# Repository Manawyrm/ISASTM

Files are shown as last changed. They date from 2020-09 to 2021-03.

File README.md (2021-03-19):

ISASTM
=============================

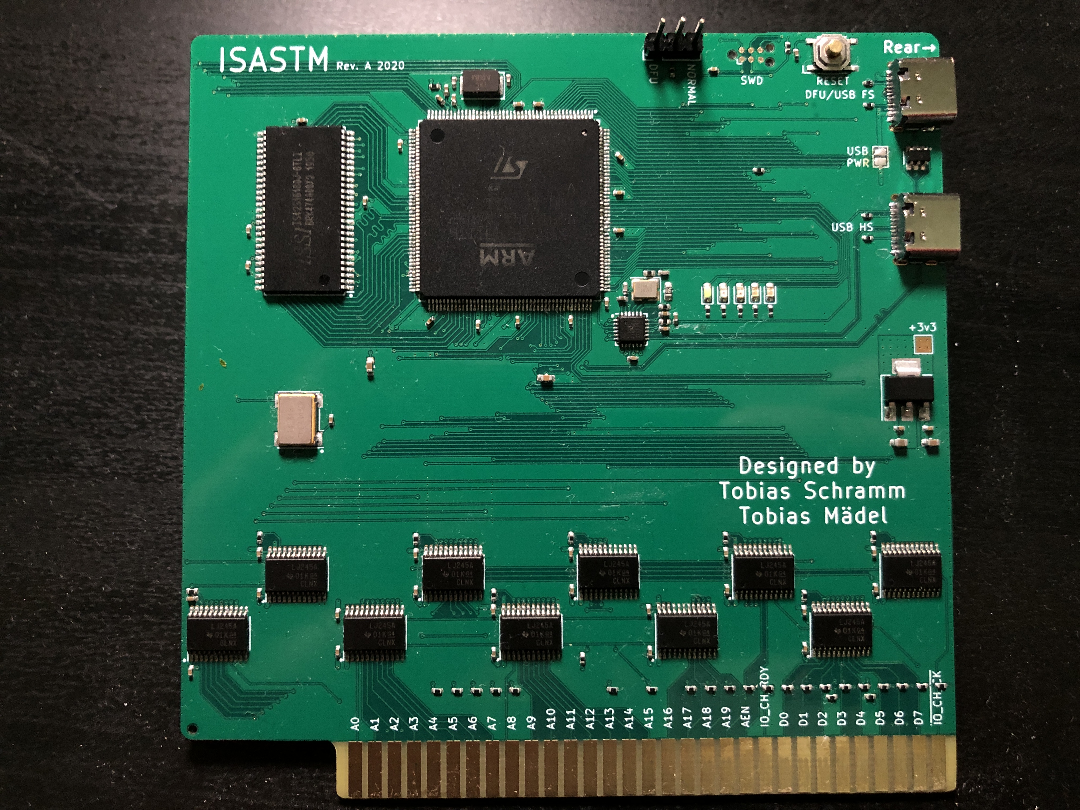
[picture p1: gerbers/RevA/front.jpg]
Photo of ISASTM PCB


### Overview

ISASTM is an ISA host using a STM32H743 CPU, 32 MiB SDRAM and USB 2.0 Full-Speed / High-Speed.  
It can enable ISA cards to be used inside a VM or even emulate an x86 PC internally with an external ISA bus. 

The card is designed to be used with an ISA backplane, which supplies power and connects the ISA slots.  
The design is optimized for automated assembly at [JLCPCB](https://jlcpcb.com/DDE). 

### Errata Rev. A
- Signal integrity issues, level shifters seem to drive the bus too hard. Maybe 33R series resistance.
- Reset line is missing a pull up on the ISA bus/HV side
- USB 2.0 High speed (480 MBit/s) untested, might not work.

### Additional info

[Firmware](https://github.com/Manawyrm/ISASTM-Firmware)  
[Schematic](https://github.com/Manawyrm/ISASTM/blob/master/gerbers/RevA/ISASTM.pdf)  
  
[Twitter: Project thread](https://twitter.com/Manawyrm/status/1302558858360033280)  

### Credits
Thanks to [@Toble_Miner](https://github.com/TobleMiner) for layouting the PCB!

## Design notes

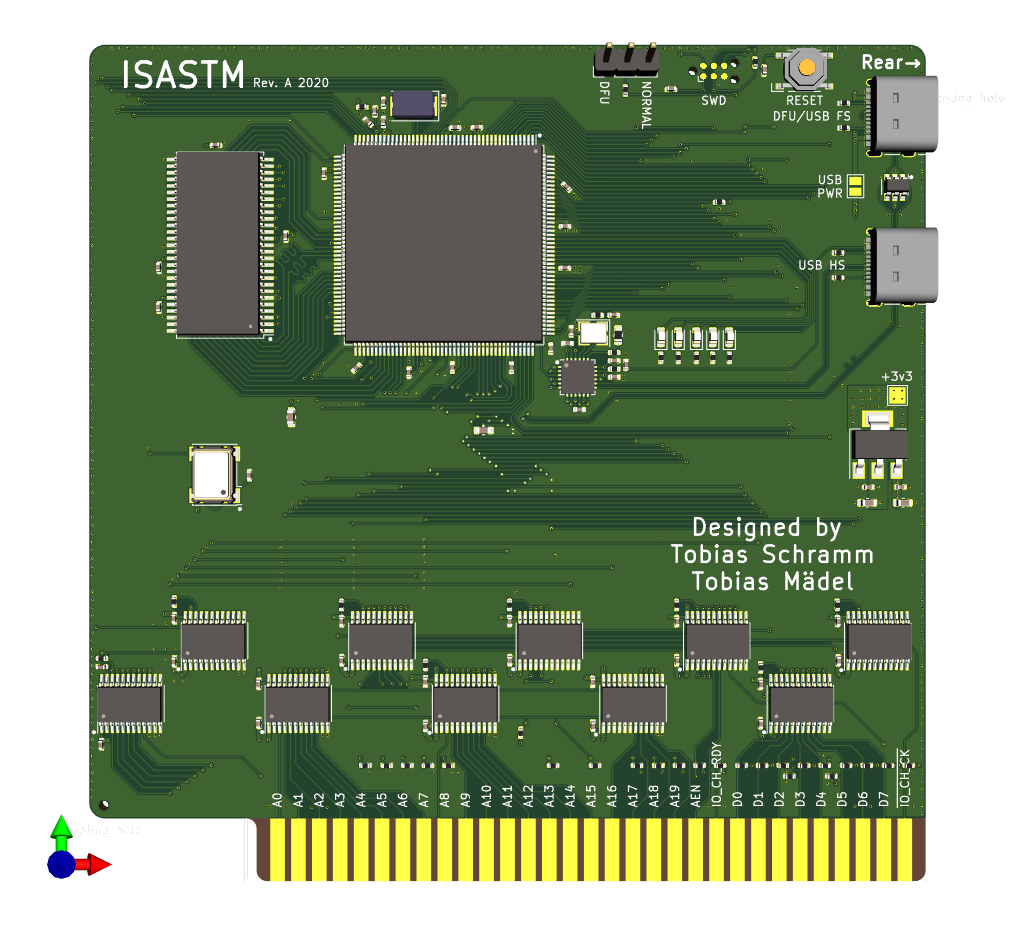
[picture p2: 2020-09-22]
gerbers/RevA/front.png

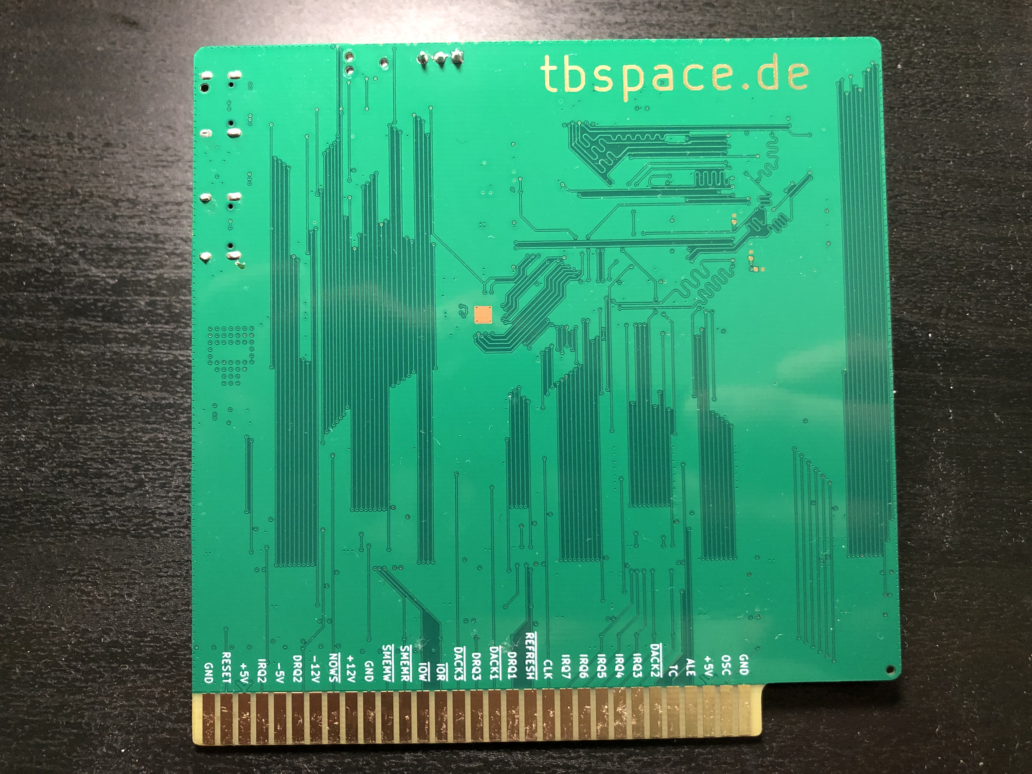
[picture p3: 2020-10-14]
gerbers/RevA/back.jpg

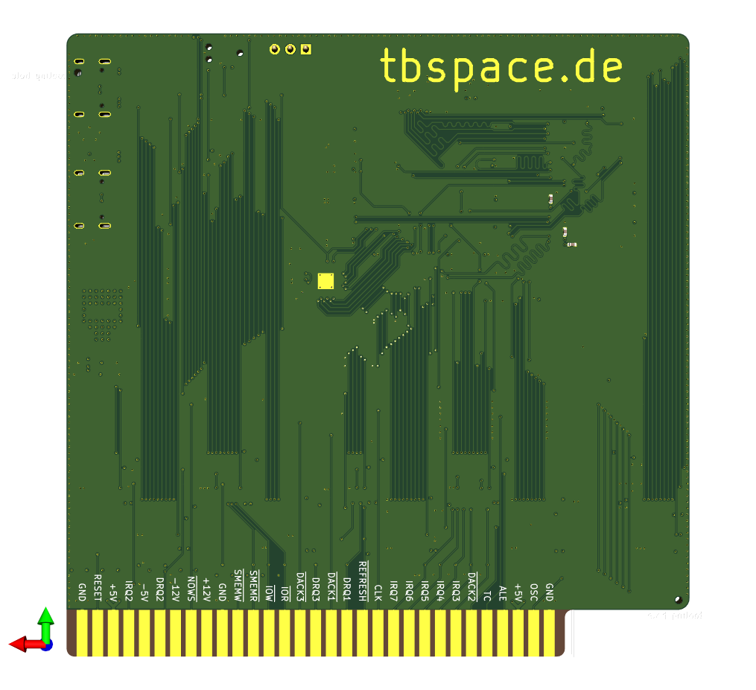
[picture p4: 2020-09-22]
gerbers/RevA/back.png

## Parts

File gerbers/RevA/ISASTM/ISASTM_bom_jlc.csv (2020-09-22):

Comment | Designator | Footprint | LCSC Part #
2.2u | C1,C2 | C_0603_1608Metric | C23630
20p | C5,C6 | C_0402_1005Metric | C1554
1u | C7,C33,C11,C4,C10 | C_0402_1005Metric | C52923
6.8pF | C8,C3 | C_0402_1005Metric | C1576
100n | C13,C16,C20,C24,C27,C29,C22,C31,C36,C14,C17,C21,C25,C28,C32,C37,C15,C19,C23,C26,C30,C35,C38,C9,C12,C39,C42,C44,C46,C48,C40,C52,C54,C56,C58,C50,C43,C45,C47,C49,C41,C53,C55,C57,C59,C51 | C_0402_1005Metric | C1525
10u | C18 | C_0603_1608Metric | C19702
22u | C34 | C_0603_1608Metric | C59461
White | D1 | LED_0603_1608Metric | C2290
Red | D2 | LED_0603_1608Metric | C2286
Yellow | D3 | LED_0603_1608Metric | C72038
Green | D4 | LED_0603_1608Metric | C72043
Blue | D5 | LED_0603_1608Metric | C72041
10k | R1,R7,R3,R4,R5,R6,R9,R10,R11,R12 | R_0402_1005Metric | C25744
10R | R2 | R_0402_1005Metric | C25077
100k | R8,R41,R42,R43,R44,R45,R46,R47,R48,R29,R30,R31,R32,R33,R34,R26,R27,R28 | R_0402_1005Metric | C25741
5.1k | R13,R14,R15,R16,R21,R22,R23,R24,R25 | R_0402_1005Metric | C25905
1M | R17 | R_0402_1005Metric | C26083
20k | R18 | R_0402_1005Metric | C25765
7.5k | R19 | R_0402_1005Metric | C25918
560R | R20 | R_0603_1608Metric | C23204
1k | R35 | R_0402_1005Metric | C11702
4.7k | R36,R37,R38,R39,R40,R49 | R_0402_1005Metric | C25900
Reset | SW1 | TS-1187A-X-X-X | C318887
STM32H743IITx | U1 | LQFP-176_24x24mm_P0.5mm | C89597
IS42S16160J-6TLI | U2 | TSOP-II-54_22.2x10.16mm_P0.8mm | C91278
AMS1117-3.3 | U5 | SOT-223-3_TabPin2 | C6186
SN74AVC8T245PW | U9,U3,U4,U10,U6,U7,U8,U13,U11,U12 | TSSOP-24_4.4x7.8mm_P0.65mm | C7859
SRV05-4 | U14 | SOT-23-6 | C85364
14.31818 MHz | X1 | Oscillator_SMD_SeikoEpson_SG8002CA-4Pin_7.0x5.0mm | C70517
26 MHz | Y1 | Crystal_SMD_3225-4Pin_3.2x2.5mm | C91747
8 MHz | Y2 | Crystal_SMD_5032-2Pin_5.0x3.2mm | C115962

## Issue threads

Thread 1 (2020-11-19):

List of tested ISA cards

kuenzign, 2020-11-19:
This looks like a great project and it's very exciting.  I think that in order to gain more support from the community, it would be a good idea to provide a list of cards that have been tested with the ISASTM (showing which cards **do not** work and cards that **do** work).  Personally, I have been hoping that ISA floppy controllers would work, but that's probably a bit of a pipe dream.  Thanks for the hard work!

Manawyrm, 2020-11-19:
Hey,

so, in general every 8bit ISA card is able to be supported.
There are 2 main issues:
a) real-time operation
b) USB latency / frame-timings

The other issues like missing/very broken DMA support are just software problems and could be fixed in the firmware.

The lack of real-time operation (because the emulator isn't always running at 100% CPU speed and can vary it's frequency by quite a bit) is normally not an issue, but for specific applications like measurements, motor control (think old CNC machine controllers, etc.) this will be a big issue. I don't see any way to support this kind of device.

The USB standard requires a minimum frame time of 1ms per frame (125µs for USB 2.0 HS), which means you will need at least 2ms for a single byte transfer. Writing data can be done a lot more efficient/faster with clever coding, but reads are always bottlenecked by this.

I have successfully used:
- a floppy controller card (with a flash floppy USB emulator thingy)
- a serial port card
- a parallel port card
- a port 80h diagnostic card
- several sound blaster card (using the AdLib functionality)
- a Creative Gameblaster card
- several VGA cards
- a RTL8019 network card

Things that don't work (and why):
- Sound Blaster (digital sound, needs properly working DMA support, pretty sure fixable)
- IDE controller cards (need upper 16bit IRQs and 16bit data for ATAPI commands, no supported by hardware)

In general, the USB idea was pretty okay for a proof-of-concept, but if you would want to actually use this thing for any real usage, the board would need to be redesigned to use something like an FPGA and use a bus like PCI.
Talking via Thunderbolt/PCIe/PCI to a media bridge and letting it map the ISA bus 1:1 would work much, much better.
Interrupts could be handled as MSIs, DMA would just be done as writes/reads to a mailbox (probably?!).

But I don't think I'm going to implement that anywhere in the near future.

Best regards,
Tobias

toncho11, 2020-12-03:
Hi,

Great project!

So how does it work exactly? I want to use a 360 KB floppy and controller on Windows 10.
So I need to build and put your card and the floppy controller on an ISA backplane.
But then we need a Windows driver that will emulate the floppy on Windows? This part I do not understand.

Manawyrm, 2020-12-04:
Hi toncho,

this project is converts a set of USB messages to actions on an ISA bus.
In theory, yes, you could build a Windows driver for it.
I don't think that's a useful thing, though.

What you'd do is start an emulator (like PCem) and do your work in there (with the "real" floppy being pass-through).

The project is not a point where it is usable for any proper work, at all, though.
I would NOT recommend you go build one of these, unless you want to find out every single little detail about the ISA bus.

If you want to work with floppy drives, use Greaseweazle, KryoFlux or similar:
https://github.com/keirf/Greaseweazle
https://www.kryoflux.com/
They are easier to assemble and will do what you need, much better and easier.

Best regards,
Tobias

laf0rge, 2022-01-28:
I have a number of questions about this project, and since there seems to be no mailing-list or forum, I'm hijacking this github issue for it..

> so, in general every 8bit ISA card is able to be supported. [...]]

Is there a specific reason to go for 8-bit ISA only?  The rather high-end microcontroller chosen should have plenty of additional I/O pins around?

> The USB standard requires a minimum frame time of 1ms per frame (125µs for USB 2.0 HS), which means you will need at least 2ms for a single byte transfer. Writing data can be done a lot more efficient/faster with clever coding, but reads are always bottlenecked by this.

The question here is whether 125us (x2) is "good enough" for most use cases or not.  Sure, FS-USB 2ith 1ms (x2) is probably stretching it a bit too far for any but the most trivial use cases.

> In general, the USB idea was pretty okay for a proof-of-concept, but if you would want to actually use this thing for any real usage, the board would need to be redesigned to use something like an FPGA and use a bus like PCI. Talking via Thunderbolt/PCIe/PCI to a media bridge and letting it map the ISA bus 1:1 would work much, much better. Interrupts could be handled as MSIs, DMA would just be done as writes/reads to a mailbox (probably?!).

That's of course a completely different complexity (schematics, layout, cost, ...), and a bit overkill for the good old ISA, IMHO.

btw; any spcific reason for putting 32MiB of SDRAM in the design?  The use case of translating small MMIO / PIO transactions between USB transfers and the ISA bus doesn't really look like anything that would be very memory-heavy.  Just trying to find the reason for the design decision to understand the project better.

Thanks!

Manawyrm, 2022-01-28:
> since there seems to be no mailing-list or forum

True, I have a nasty habit of abandoning projects after I get bored with them :laughing:
But you know my Twitter account and IRC handle :)

> Is there a specific reason to go for 8-bit ISA only?

Yes, it's a 4-layer board and back then going over 10x10cm was very expensive (for a hobby project) at JLCPCB.
I think that's changed by now, so a second revision might be useful.

> The question here is whether 125us (x2) is "good enough" for most use cases or not.

Yes, but USB 2.0 is broken on the card. I'm still not a fan of USB, but I'm fairly certain that the STM32 is incompatible with the USB PHY due to a hardware bug. There are other ULPI PHYs that should be compatible (USB3300 maybe? untested.).

I wanted to do "retro fun" stuff like attaching VGA cards and sound cards via USB, especially VGA scrolling via 1ms latency was getting very painfully slow.
For stuff like machine control, sensor aquisition, etc. it might be perfectly fine?
Just a small caveat: IRQ support is experimental at best, DMA support is practically non-existant. I/O works pretty well.

>  any spcific reason for putting 32MiB of SDRAM in the design?

Yes! :smile:
We've ported a full 486 emulator onto the plattform and were able to get the card to run a "full" computer all by itself.
Unfortunately, it only boots into the BIOS and it fails after the memory check (which only goes up to 640KB, although 4MB are available). I think it's something to do with 32bit alignment, but I wasn't able to figure out what the exact issue is.

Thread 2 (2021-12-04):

This is really neet and thinking of forking it.

WarlockD, 2021-12-04:
Ever thought of using a Cypress chip?  Its basically an ARM with some logic blocks to do stuff like bus arbitration and has a built in usb 2.0 port.  Whats best is it can run at 5 volts at 48mhz.  I think I will experiment with it a bit to see if I can get it to work but either way love your project and be building it as soon as I find the chilps:P

Manawyrm, 2021-12-04:
Yup, I also have an FX3 USB3.0 board here to play around with.

In the end, USB is just the wrong protocol for this kind of application. Each bus transaction takes a very long fixed time due to USB frame lengths and this makes the result almost unusably slow.

A better interface like PCIe (or Thunderbolt), maybe Firewire would be required for proper operation.

laf0rge, 2022-01-28:
> A better interface like PCIe (or Thunderbolt), maybe Firewire would be required for proper operation.

did you ever think of LPC-to-ISA bridges?  There are quite a number of x86 boards around where access to LPC is possible.

Manawyrm, 2022-01-28:
Yes! I sniffed around on the LPC of a machine I had, but the mapped memory regions were quite limited.

I was thinking about doing something like a PCI card with 2 memory BARs:
1 memory BAR would translate all R/W into ISA I/O R/W
1 memory BAR would translate all R/W into ISA Memory R/W
and maybe another space for a mailbox for interrupts, DMA, etc.

That should be very easy to implement in x86 emulators and should also work on something like a Raspberry Pi. (I'm still dreaming of an ISA card with a Compute Module 4, which could emulate the CPU while having real peripherals)

Manawyrm, 2022-01-28:
I actually have a nice PCI devboard here and was playing around with it, but I'm not experienced enough with FPGAs yet to implement the timings and state machine for the PCI->ISA conversion.
Then I also accepted a new job, so my time for retro fun is even more limited :cry:

laf0rge, 2022-01-28:
> Yes! I sniffed around on the LPC of a machine I had, but the mapped memory regions were quite limited.

I'm pondering to build something around a fintek LPC2ISA bride, and hooking that up to the LPC header of a PC-Engines APU2.  That's a neat little fanless embedded x86_64 board (with schematics available). And as it has the LDRQ0# signal connected to the LPC header, so even ISA DMA should be possible.

> I was thinking about doing something like a PCI card with 2 memory BARs: 1 memory BAR would translate all R/W into ISA I/O R/W 1 memory BAR would translate all R/W into ISA Memory R/W and maybe another space for a mailbox for interrupts, DMA, etc.

interesting idea.  But indeed more a HDL/FPGA kind of task, rather than a board-level circuit design aroun existing ICs + software development kind of task.  The latter of which seem to be falling more into both of our comfort zone..

WarlockD, 2022-03-03:
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

I agree and it looks somone beat us to the punch.
https://www.aliexpress.com/item/1005002622355949.html?spm=a2g0o.order_list.0.0.21ef1802t2BaDU
Its a PCIE bus to ISA converter board.  I think its more designed so you can interface embeded pcie things with leagcy electronics, but its 5v safe, LQFP-64 small, has a seperate spi and a few gpio independent pins with seperate 8 bit data/address lines.
I ordered one of these and the CH368 Development board.  The main diffrence is the 368 supports a 16 bit address space and a 32bit word data path with separate IOP and MEM access pins.  Hell there are even signed windows 10 drivers for these things for both passthough and direct development.

Won't really know how well it works till I get it latter this month though.  The chip maker has the drivers and a header for its dll and its simple enough to use.  Funny enough it looks like this thing has been out since 2011 (At least that's the date on the header) so kind of surprised they never advertised it more.

WarlockD, 2022-03-03:
As a side note, I also have evaluated the Arstech device, thinking I rather drop a pound to save a ton.  Nope.  ARG the rant I can go on that API when all it is just a FX2 directly connected to the ISA bus.  It works though, but its stupid app is running 100% on one of the cpus and does cross process function direct pointer calls, *shutter*

Manawyrm, 2022-03-03:
@WarlockD The CH368 actually looks really promising!
Have you found a dev board for the CH368 with an ISA connector directly attached?

WarlockD, 2022-03-10:
Sadly no, I got both of them in.  Intresting about them is they both have this 4 pin connector that has 8bits of address, 8bits of data and all the signal lines.  So I could run a 4pin ribbon cable to say a backplane.  The CH368 has a second 40 pin connector that has the other 24bit data, the upper 8bit address and singles for the spi/ extra gpio etc.

Right now trying to get a computer together for it and going to see if I can get my soundblaster to work on it.  It only needs io to run.  Also found some linux drivers for this to.

Real question is how to build something from this.  It dosn't look like you need to use buffers like you would on the ISASTM, however since its a pcie bus, your limited to like a 2 foot usb 3.0 cord if your extending it that way.  I think you could get a way with a 40 pin ide cable to an adaptor plate.  Humm I will see if I can make such a plate, I wonder if they make cases that take two motherboards.

jamesfmackenzie, 2023-09-24:
Catching up on this thread in 2023! Did you ever make progress with the CH368? I noticed this newer revision. Looks similar to the older CH368 but with an onboard FPGA:

Pcie Development Board CH368 Development Board Pcie-FPGA Development Board
https://a.aliexpress.com/_mqNw0Bg

Does that hold some extra interest?

WarlockD, 2023-09-28:
Not really, got pulled away by other things.  I did mange to spider wire together the CH368 16bit board to a vga card and get it to run.  The issue I couldn't get away from though is that I couldn't think of a way for it to emulate something a bios would recognize.  This is an interface from PCIE to 16bit ISA, not the other way around so I cannot monitor things like address changes or such.  Maybe as a connection to a CM4 raspberry pi (That's the pi that has a PCIE exposed) You could use a set of tri-state registers and monitor the isa bus, but I haven't scoped the connection to see if the chip can go fast enough to catch edges.  But again the chip is cheap, requires little to no external components and the driver software is easy to use.

Honestly I have been looking at those dirt cheap 20k LUT Chinese FPGA's.  Like under 20 bucks.  That's more than enough for a complete NES and more than enough for any kind of video emulation.  But again, things like this keep me moving around without focus so sorry I couldn't be much more help.

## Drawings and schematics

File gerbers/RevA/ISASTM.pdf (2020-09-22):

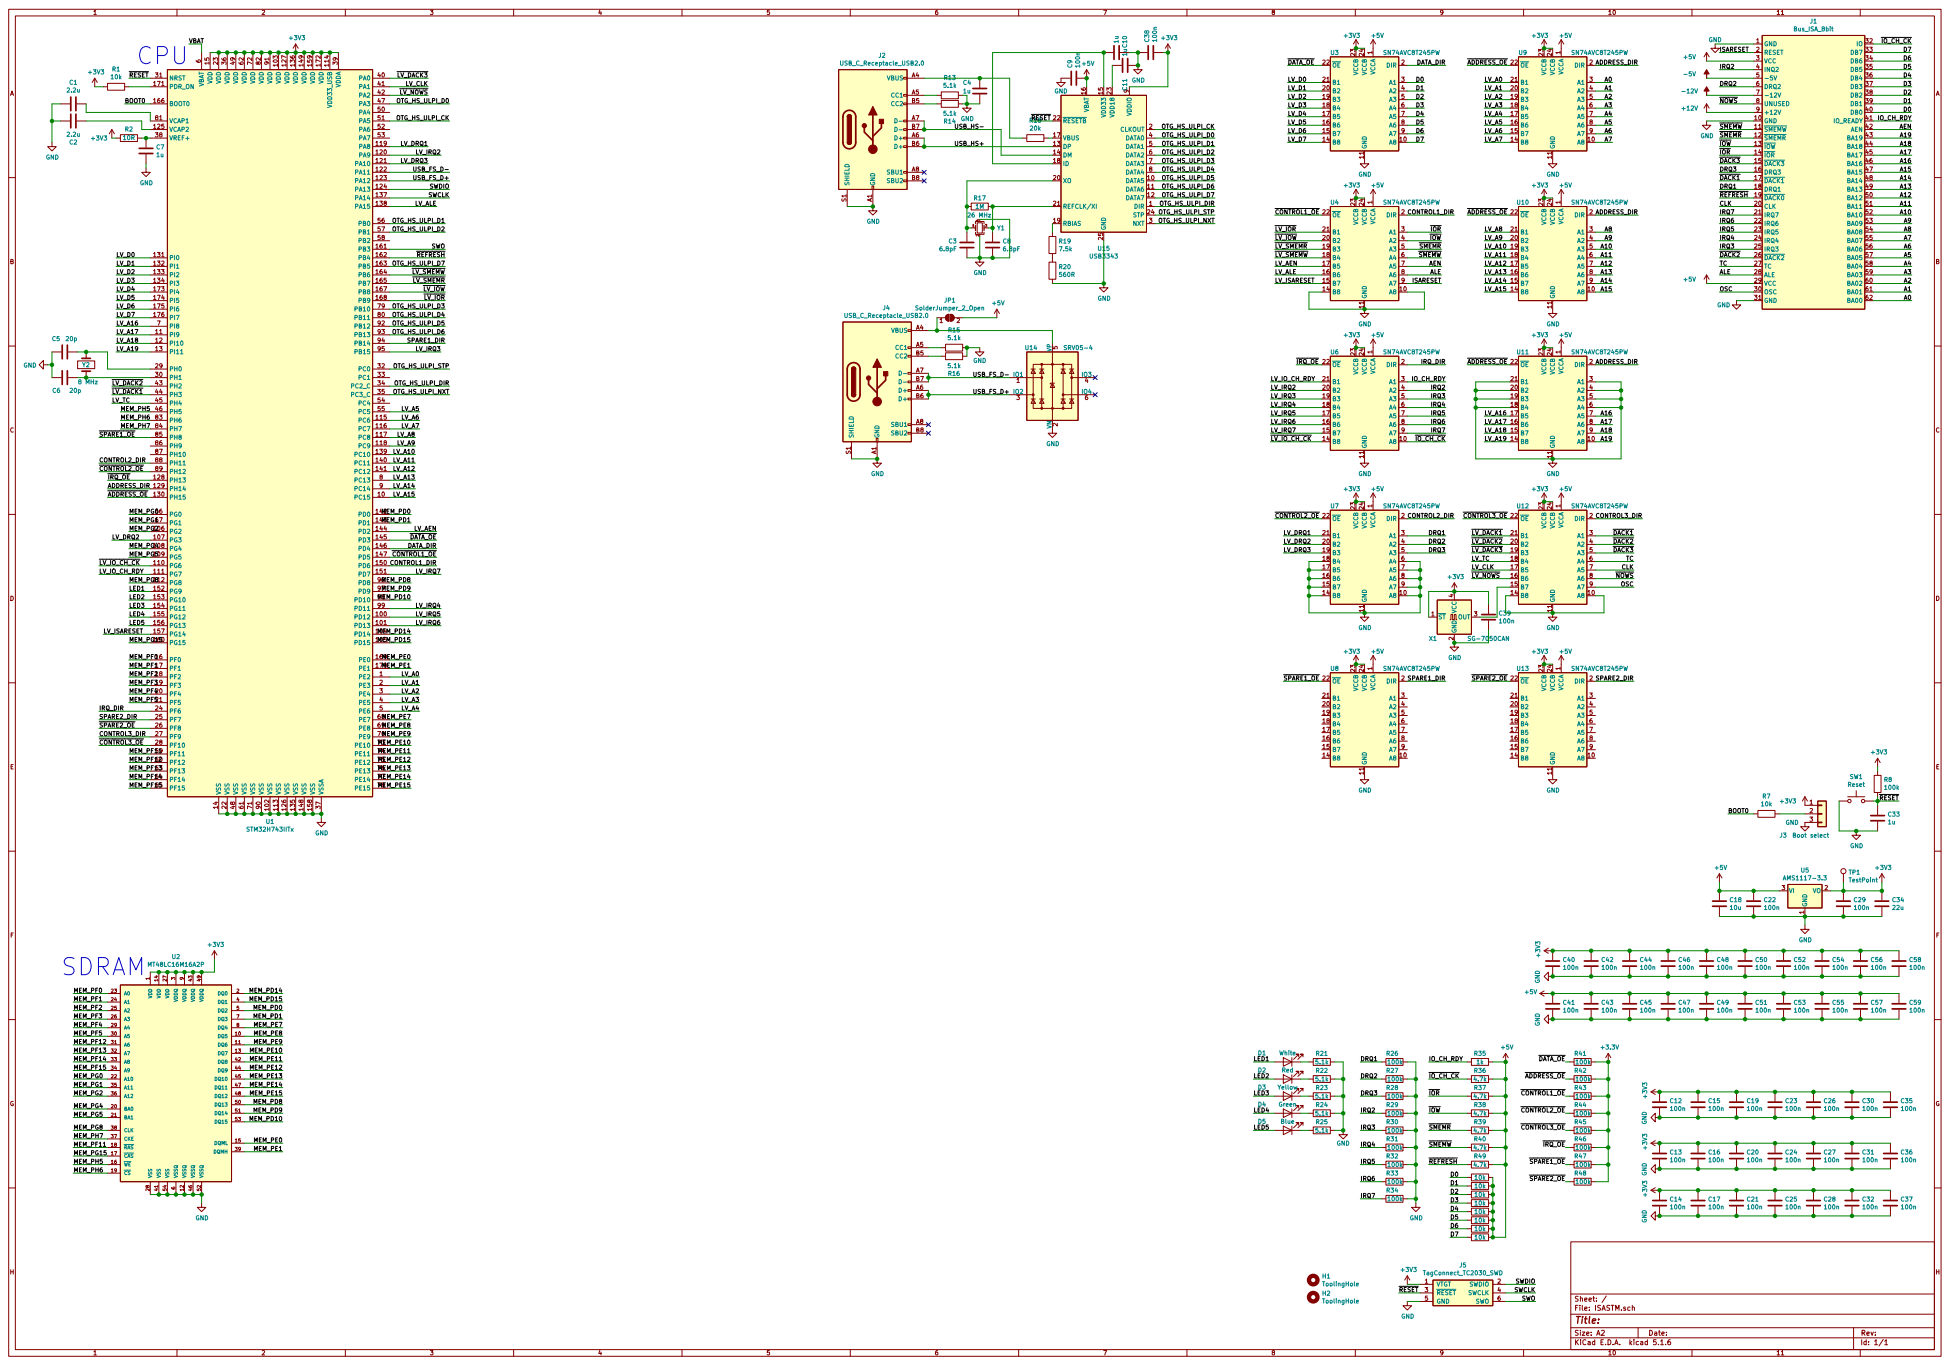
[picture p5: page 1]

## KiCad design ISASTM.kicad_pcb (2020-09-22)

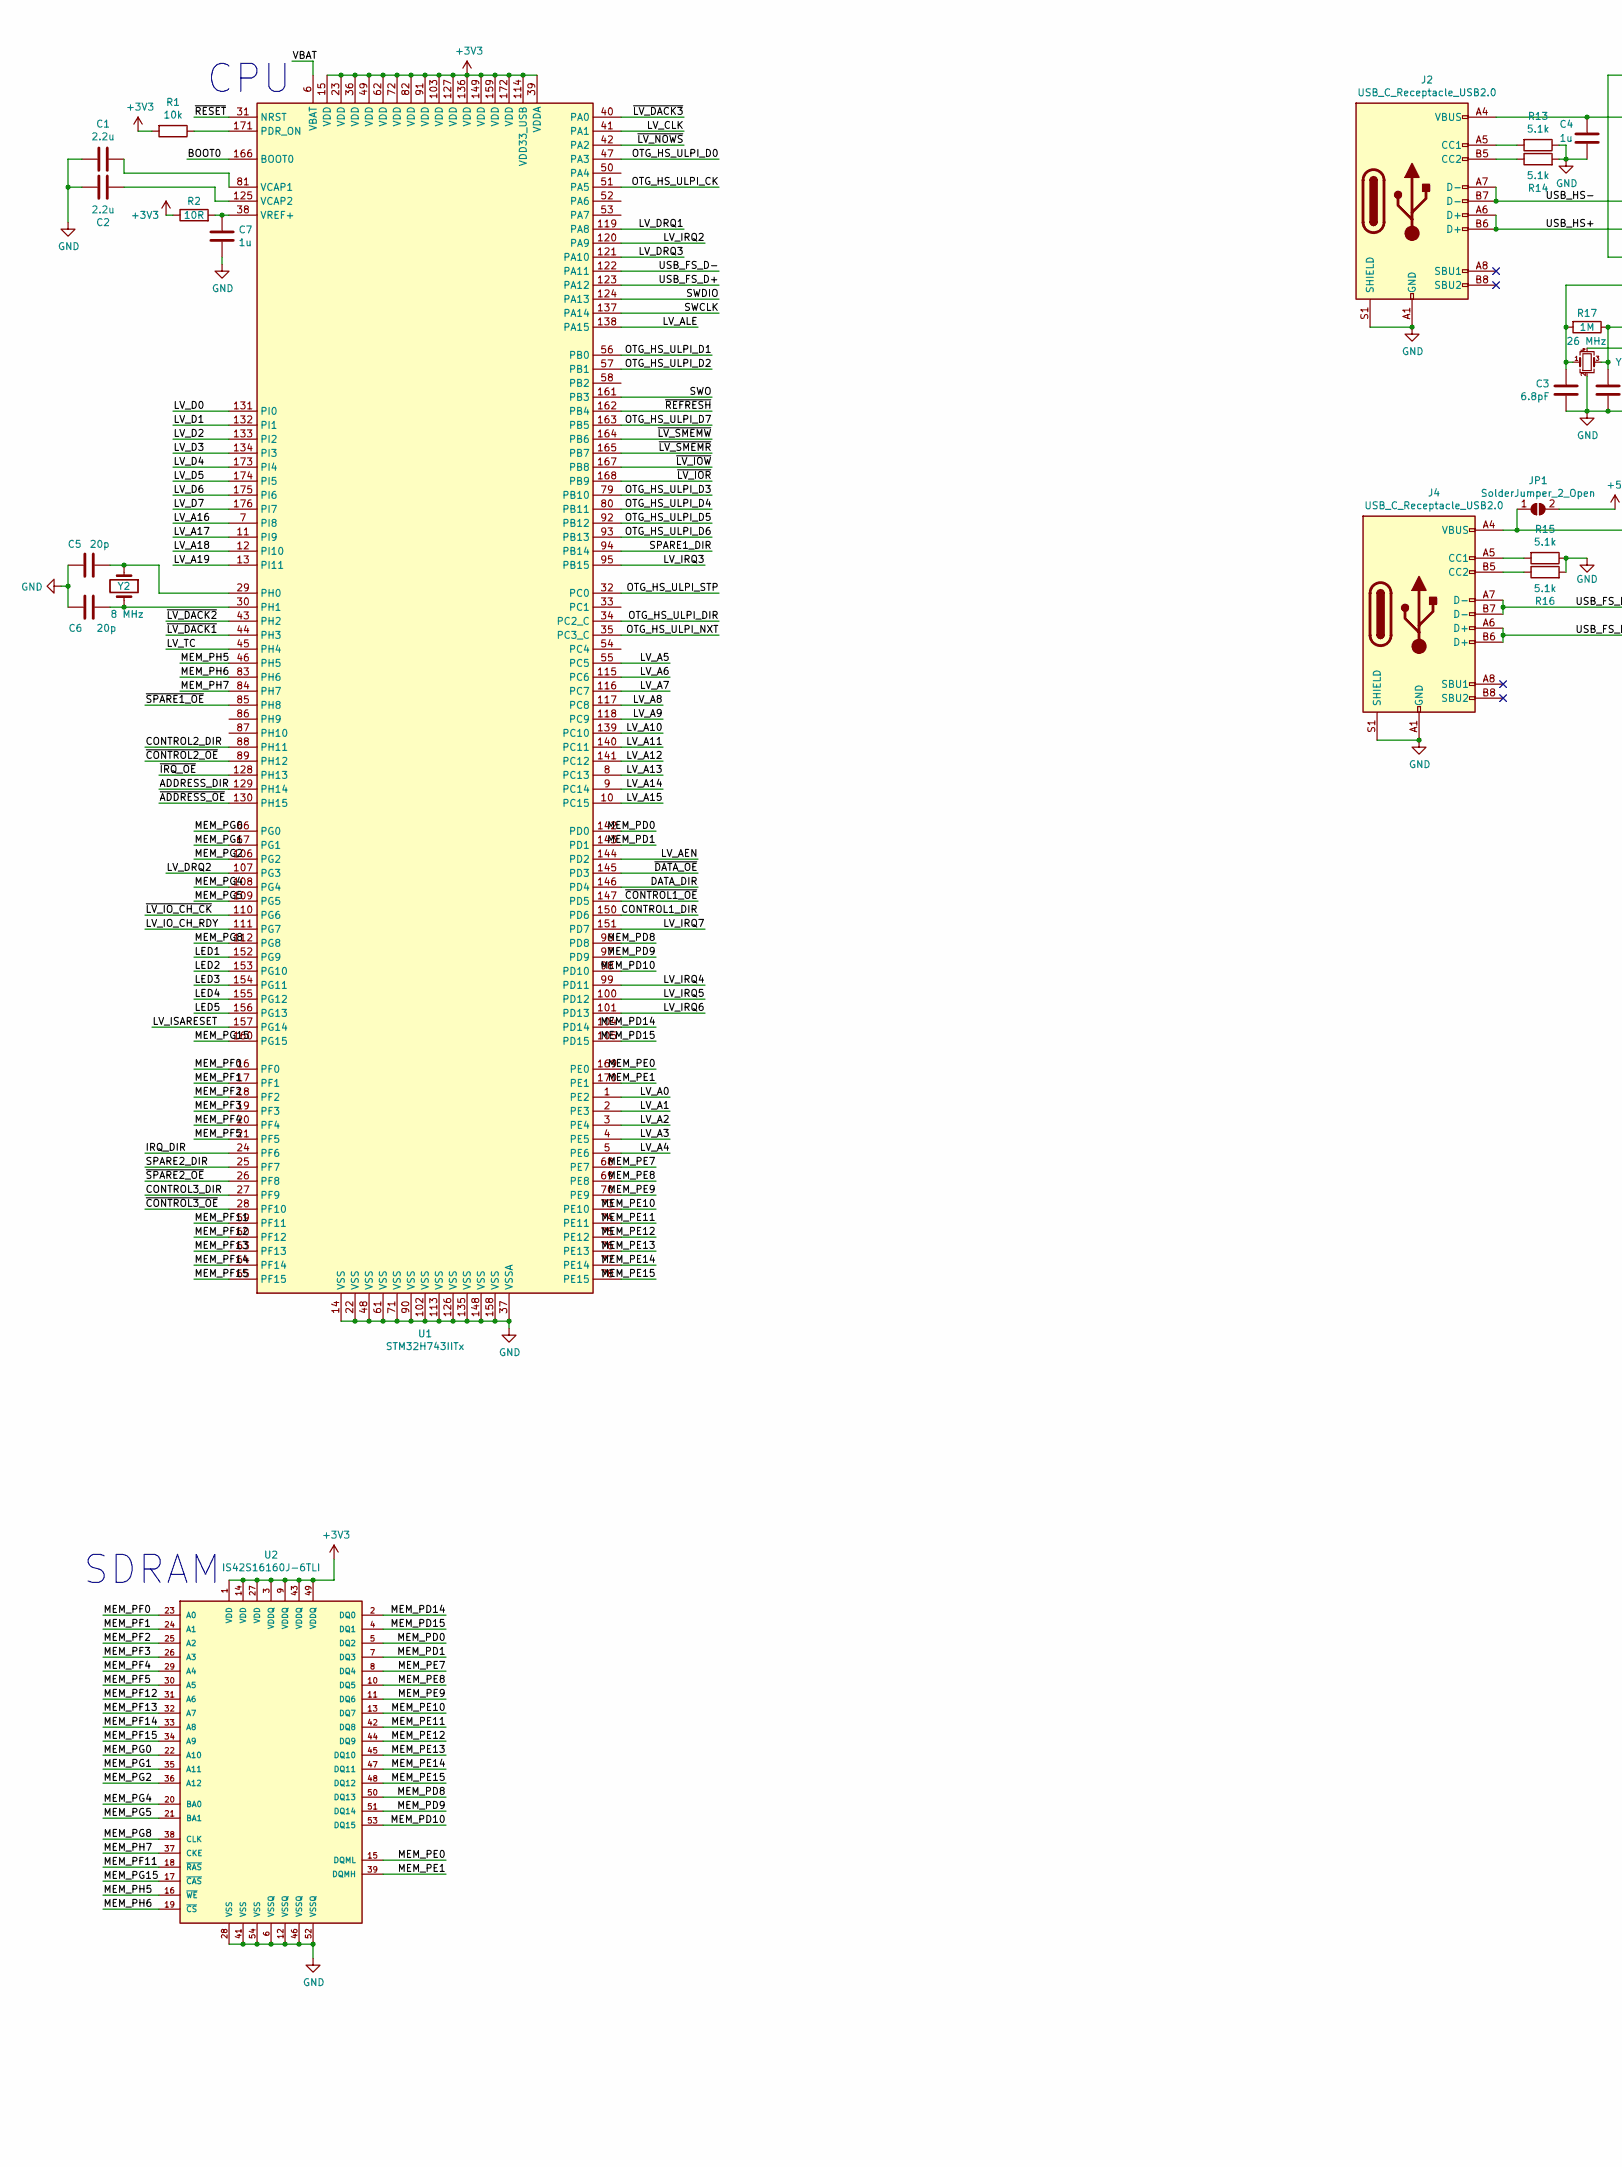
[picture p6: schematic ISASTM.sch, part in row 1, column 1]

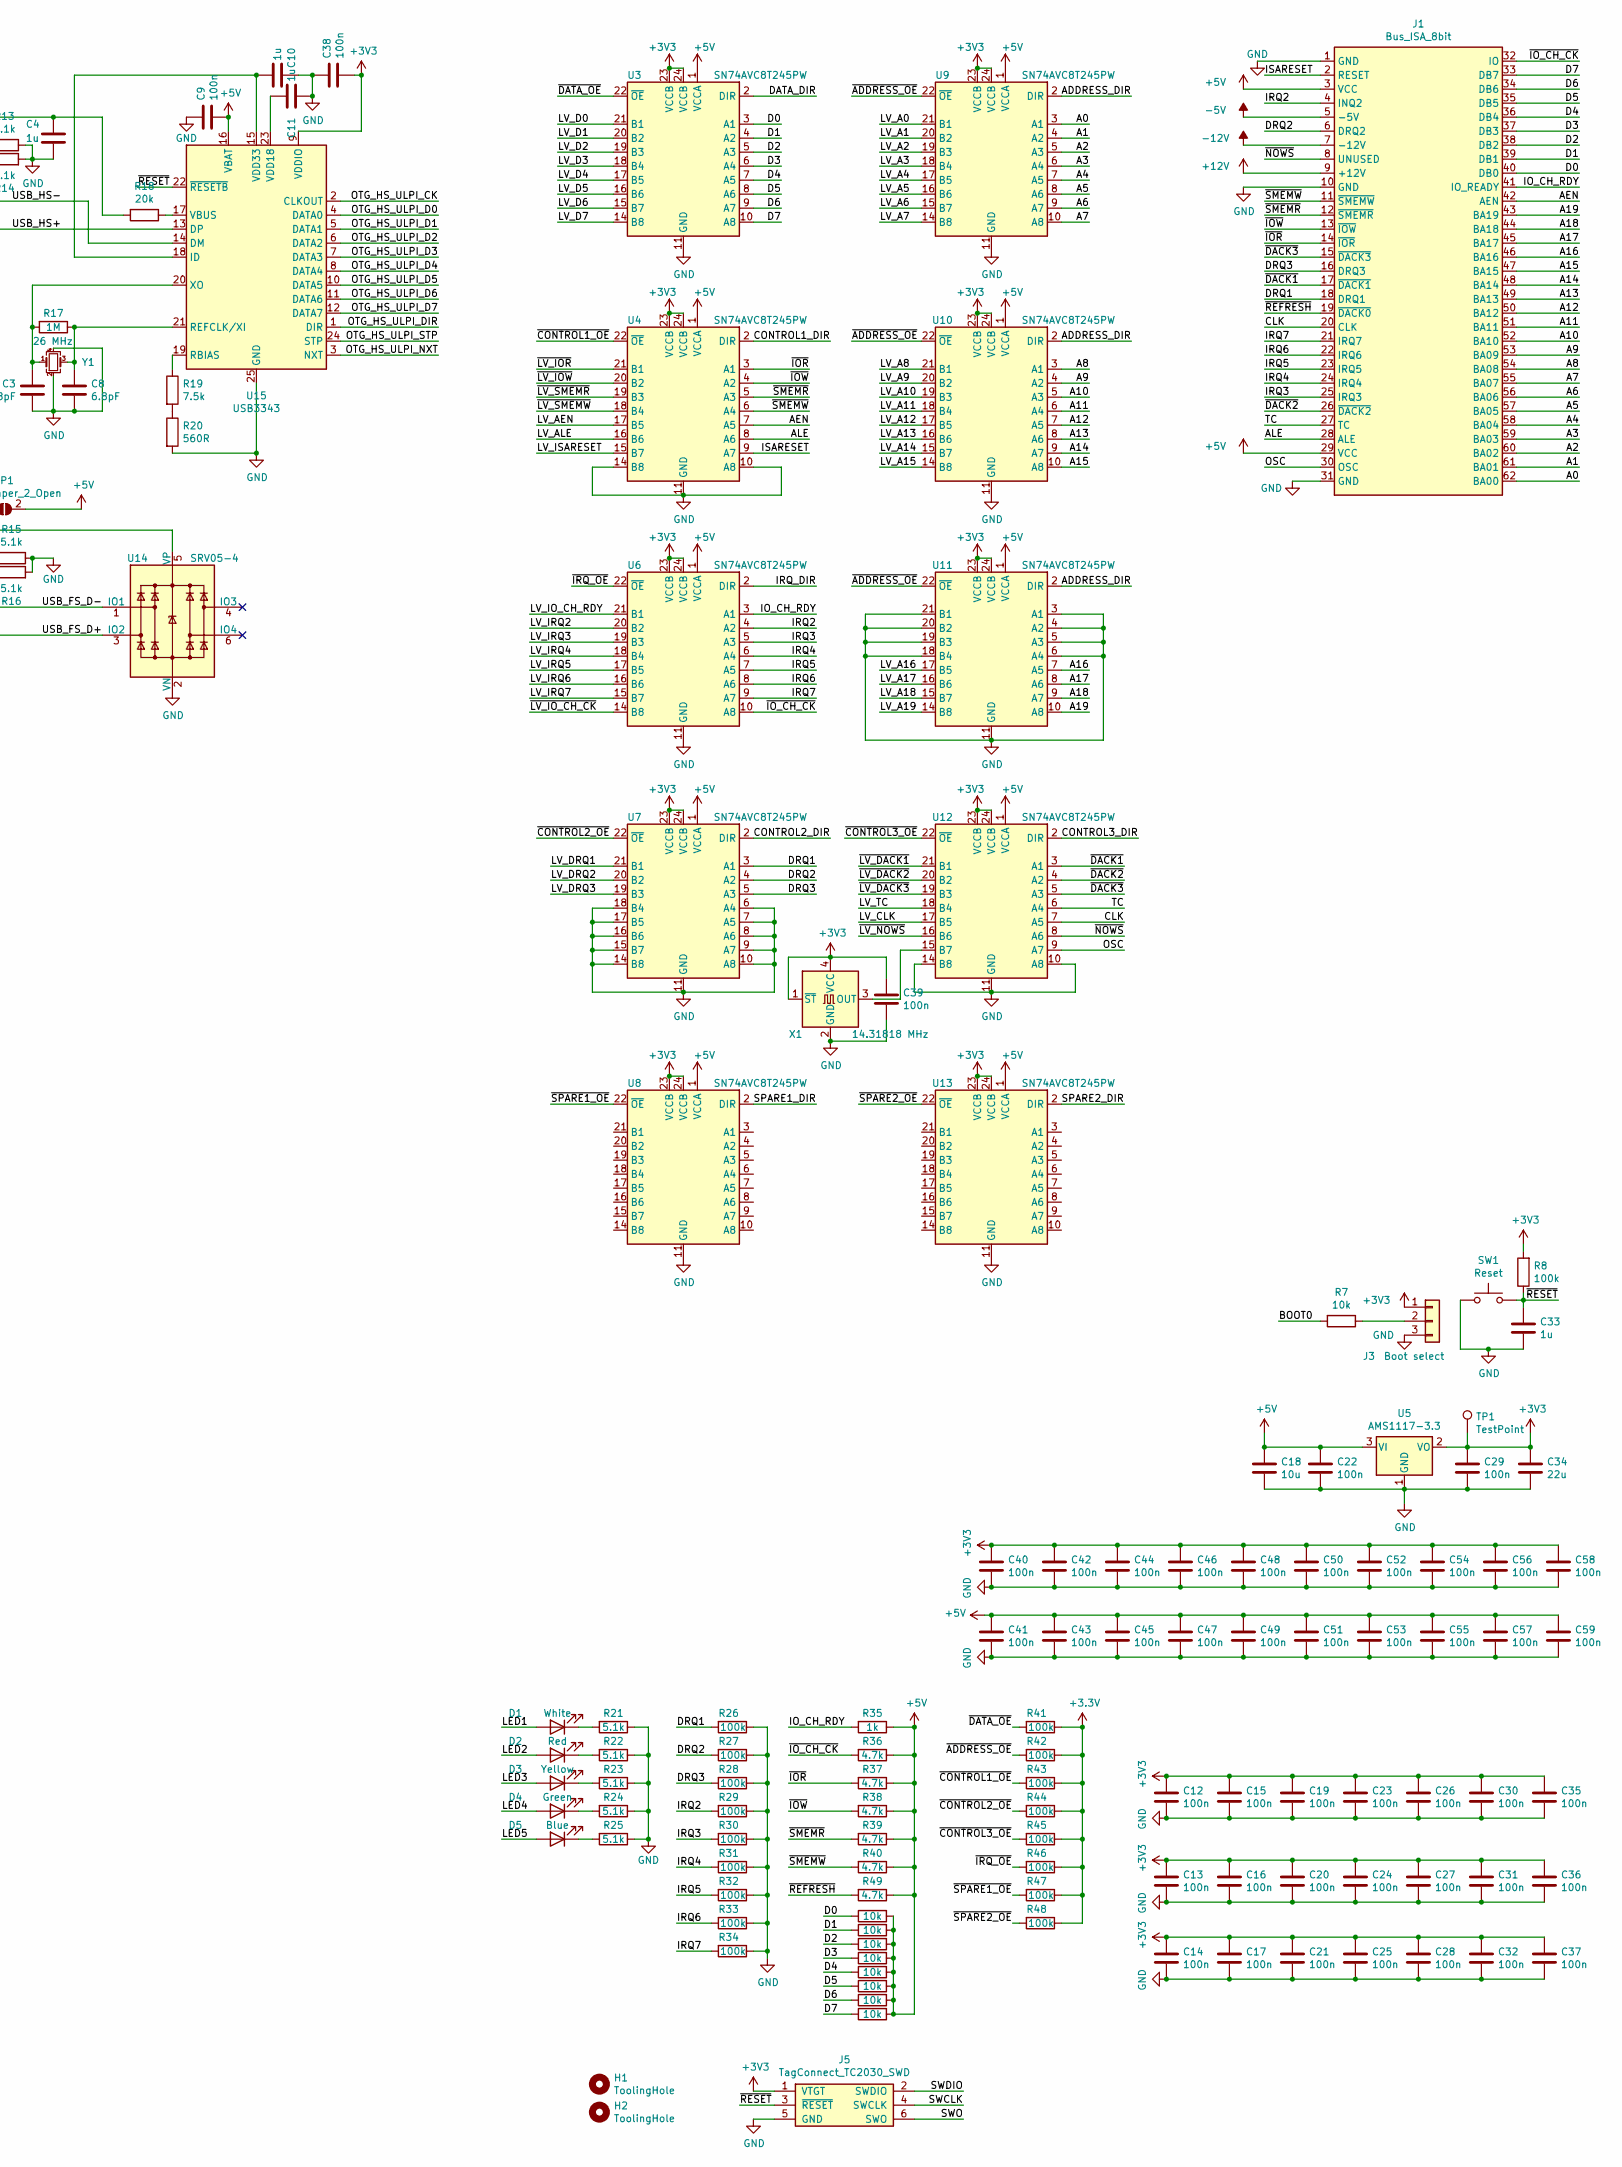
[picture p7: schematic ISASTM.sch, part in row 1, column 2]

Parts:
C1, C2: 2.2u; C_0603_1608Metric; LCSC C23630
C3, C8: 6.8pF; C_0402_1005Metric; LCSC C1576
C4, C7, C10, C11, C33: 1u; C_0402_1005Metric; LCSC C52923
C5, C6: 20p; C_0402_1005Metric; LCSC C1554
C9, C12, C13, C14, C15, C16, C17, C19, C20, C21, C22, C23, C24, C25, C26, C27, C28, C29, C30, C31, C32, C35, C36, C37, C38, C39, C40, C41, C42, C43, C44, C45, C46, C47, C48, C49, C50, C51, C52, C53, C54, C55, C56, C57, C58, C59: 100n; C_0402_1005Metric; LCSC C1525
C18: 10u; C_0603_1608Metric; LCSC C19702
C34: 22u; C_0603_1608Metric; LCSC C59461
D1: White; LED_0603_1608Metric; LCSC C2290
D2: Red; LED_0603_1608Metric; LCSC C2286
D3: Yellow; LED_0603_1608Metric; LCSC C72038
D4: Green; LED_0603_1608Metric; LCSC C72043
D5: Blue; LED_0603_1608Metric; LCSC C72041
H1, H2: ToolingHole; ToolingHole_JLCSMT
J1: Bus_ISA_8bit; Conn_Edge_PCB_ISA8
J2, J4: USB_C_Receptacle_USB2.0; USB_C_Receptacle_Palconn_UTC16-G
J3: Boot select; PinHeader_1x03_P2.54mm_Vertical
J5: TagConnect_TC2030_SWD; Tag-Connect_TC2030-IDC-NL_2x03_P1.27mm_Vertical
JP1: SolderJumper_2_Open; SolderJumper-2_P1.3mm_Open_Pad1.0x1.5mm
R1, R3, R4, R5, R6, R7, R9, R10, R11, R12: 10k; R_0402_1005Metric; LCSC C25744
R2: 10R; R_0402_1005Metric; LCSC C25077
R8, R26, R27, R28, R29, R30, R31, R32, R33, R34, R41, R42, R43, R44, R45, R46, R47, R48: 100k; R_0402_1005Metric; LCSC C25741
R13, R14, R15, R16, R21, R22, R23, R24, R25: 5.1k; R_0402_1005Metric; LCSC C25905
R17: 1M; R_0402_1005Metric; LCSC C26083
R18: 20k; R_0402_1005Metric; LCSC C25765
R19: 7.5k; R_0402_1005Metric; LCSC C25918
R20: 560R; R_0603_1608Metric; LCSC C23204
R35: 1k; R_0402_1005Metric; LCSC C11702
R36, R37, R38, R39, R40, R49: 4.7k; R_0402_1005Metric; LCSC C25900
SW1: Reset; TS-1187A-X-X-X; LCSC C318887
TP1: TestPoint; TestPoint_Pad_2.0x2.0mm
U1: STM32H743IITx; LQFP-176_24x24mm_P0.5mm; LCSC C89597
U2: IS42S16160J-6TLI; TSOP-II-54_22.2x10.16mm_P0.8mm; LCSC C91278
U3, U4, U6, U7, U8, U9, U10, U11, U12, U13: SN74AVC8T245PW; TSSOP-24_4.4x7.8mm_P0.65mm; LCSC C7859
U5: AMS1117-3.3; SOT-223-3_TabPin2; LCSC C6186
U14: SRV05-4; SOT-23-6; LCSC C85364
U15: USB3343; QFN-24-1EP_4x4mm_P0.5mm_EP2.6x2.6mm
X1: 14.31818 MHz; Oscillator_SMD_SeikoEpson_SG8002CA-4Pin_7.0x5.0mm; LCSC C70517
Y1: 26 MHz; Crystal_SMD_3225-4Pin_3.2x2.5mm; LCSC C91747
Y2: 8 MHz; Crystal_SMD_5032-2Pin_5.0x3.2mm; LCSC C115962

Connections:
+5V: C9.2, C18.1, C22.1, C41.1, C43.1, C45.1, C47.1, C49.1, C51.1, C53.1, C55.1, C57.1, C59.1, J1.3 (VCC), J1.29 (VCC), JP1.2 (B), R3.2, R4.2, R5.2, R6.2, R9.2, R10.2, R11.2, R12.2, R35.1, R36.1, R37.1, R38.1, R39.1, R40.1, R49.1, U3.1 (VCCA), U4.1 (VCCA), U5.3 (VI), U6.1 (VCCA), U7.1 (VCCA), U8.1 (VCCA), U9.1 (VCCA), U10.1 (VCCA), U11.1 (VCCA), U12.1 (VCCA), U13.1 (VCCA), U15.16 (VBAT)
+12V: J1.9 (+12V)
-5V: J1.5 (-5V)
-12V: J1.7 (-12V)
/A0: J1.62 (BA00), U9.3 (A1)
/A1: J1.61 (BA01), U9.4 (A2)
/A2: J1.60 (BA02), U9.5 (A3)
/A3: J1.59 (BA03), U9.6 (A4)
/A4: J1.58 (BA04), U9.7 (A5)
/A5: J1.57 (BA05), U9.8 (A6)
/A6: J1.56 (BA06), U9.9 (A7)
/A7: J1.55 (BA07), U9.10 (A8)
/A8: J1.54 (BA08), U10.3 (A1)
/A9: J1.53 (BA09), U10.4 (A2)
/A10: J1.52 (BA10), U10.5 (A3)
/A11: J1.51 (BA11), U10.6 (A4)
/A12: J1.50 (BA12), U10.7 (A5)
/A13: J1.49 (BA13), U10.8 (A6)
/A14: J1.48 (BA14), U10.9 (A7)
/A15: J1.47 (BA15), U10.10 (A8)
/A16: J1.46 (BA16), U11.7 (A5)
/A17: J1.45 (BA17), U11.8 (A6)
/A18: J1.44 (BA18), U11.9 (A7)
/A19: J1.43 (BA19), U11.10 (A8)
/ADDRESS_DIR: U1.129 (PH14), U9.2 (DIR), U10.2 (DIR), U11.2 (DIR)
/AEN: J1.42 (AEN), U4.7 (A5)
/ALE: J1.28 (ALE), U4.8 (A6)
/BOOT0: R7.2, U1.166 (BOOT0)
/CLK: J1.20 (CLK), U12.7 (A5)
/CONTROL1_DIR: U1.150 (PD6), U4.2 (DIR)
/CONTROL2_DIR: U1.88 (PH11), U7.2 (DIR)
/CONTROL3_DIR: U1.27 (PF9), U12.2 (DIR)
/D0: J1.40 (DB0), R3.1, U3.3 (A1)
/D1: J1.39 (DB1), R4.1, U3.4 (A2)
/D2: J1.38 (DB2), R5.1, U3.5 (A3)
/D3: J1.37 (DB3), R6.1, U3.6 (A4)
/D4: J1.36 (DB4), R9.1, U3.7 (A5)
/D5: J1.35 (DB5), R10.1, U3.8 (A6)
/D6: J1.34 (DB6), R11.1, U3.9 (A7)
/D7: J1.33 (DB7), R12.1, U3.10 (A8)
/DATA_DIR: U1.146 (PD4), U3.2 (DIR)
/DRQ1: J1.18 (DRQ1), R26.2, U7.3 (A1)
/DRQ2: J1.6 (DRQ2), R27.2, U7.4 (A2)
/DRQ3: J1.16 (DRQ3), R28.2, U7.5 (A3)
/IO_CH_RDY: J1.41 (IO_READY), R35.2, U6.3 (A1)
/IRQ2: J1.4 (INQ2), R29.2, U6.4 (A2)
/IRQ3: J1.25 (IRQ3), R30.2, U6.5 (A3)
/IRQ4: J1.24 (IRQ4), R31.2, U6.6 (A4)
/IRQ5: J1.23 (IRQ5), R32.2, U6.7 (A5)
/IRQ6: J1.22 (IRQ6), R33.2, U6.8 (A6)
/IRQ7: J1.21 (IRQ7), R34.2, U6.9 (A7)
/IRQ_DIR: U1.24 (PF6), U6.2 (DIR)
/ISARESET: J1.2 (RESET), U4.9 (A7)
/LED1: D1.2 (A), U1.152 (PG9)
/LED2: D2.2 (A), U1.153 (PG10)
/LED3: D3.2 (A), U1.154 (PG11)
/LED4: D4.2 (A), U1.155 (PG12)
/LED5: D5.2 (A), U1.156 (PG13)
/LV_A0: U1.1 (PE2), U9.21 (B1)
/LV_A1: U1.2 (PE3), U9.20 (B2)
/LV_A2: U1.3 (PE4), U9.19 (B3)
/LV_A3: U1.4 (PE5), U9.18 (B4)
/LV_A4: U1.5 (PE6), U9.17 (B5)
/LV_A5: U1.55 (PC5), U9.16 (B6)
/LV_A6: U1.115 (PC6), U9.15 (B7)
/LV_A7: U1.116 (PC7), U9.14 (B8)
/LV_A8: U1.117 (PC8), U10.21 (B1)
/LV_A9: U1.118 (PC9), U10.20 (B2)
/LV_A10: U1.139 (PC10), U10.19 (B3)
/LV_A11: U1.140 (PC11), U10.18 (B4)
/LV_A12: U1.141 (PC12), U10.17 (B5)
/LV_A13: U1.8 (PC13), U10.16 (B6)
/LV_A14: U1.9 (PC14), U10.15 (B7)
/LV_A15: U1.10 (PC15), U10.14 (B8)
/LV_A16: U1.7 (PI8), U11.17 (B5)
/LV_A17: U1.11 (PI9), U11.16 (B6)
/LV_A18: U1.12 (PI10), U11.15 (B7)
/LV_A19: U1.13 (PI11), U11.14 (B8)
/LV_AEN: U1.144 (PD2), U4.17 (B5)
/LV_ALE: U1.138 (PA15), U4.16 (B6)
/LV_CLK: U1.41 (PA1), U12.17 (B5)
/LV_D0: U1.131 (PI0), U3.21 (B1)
/LV_D1: U1.132 (PI1), U3.20 (B2)
/LV_D2: U1.133 (PI2), U3.19 (B3)
/LV_D3: U1.134 (PI3), U3.18 (B4)
/LV_D4: U1.173 (PI4), U3.17 (B5)
/LV_D5: U1.174 (PI5), U3.16 (B6)
/LV_D6: U1.175 (PI6), U3.15 (B7)
/LV_D7: U1.176 (PI7), U3.14 (B8)
/LV_DRQ1: U1.119 (PA8), U7.21 (B1)
/LV_DRQ2: U1.107 (PG3), U7.20 (B2)
/LV_DRQ3: U1.121 (PA10), U7.19 (B3)
/LV_IO_CH_RDY: U1.111 (PG7), U6.21 (B1)
/LV_IRQ2: U1.120 (PA9), U6.20 (B2)
/LV_IRQ3: U1.95 (PB15), U6.19 (B3)
/LV_IRQ4: U1.99 (PD11), U6.18 (B4)
/LV_IRQ5: U1.100 (PD12), U6.17 (B5)
/LV_IRQ6: U1.101 (PD13), U6.16 (B6)
/LV_IRQ7: U1.151 (PD7), U6.15 (B7)
/LV_ISARESET: U1.157 (PG14), U4.15 (B7)
/LV_TC: U1.45 (PH4), U12.18 (B4)
/MEM_PD0: U1.142 (PD0), U2.5 (DQ2)
/MEM_PD1: U1.143 (PD1), U2.7 (DQ3)
/MEM_PD8: U1.96 (PD8), U2.50 (DQ13)
/MEM_PD9: U1.97 (PD9), U2.51 (DQ14)
/MEM_PD10: U1.98 (PD10), U2.53 (DQ15)
/MEM_PD14: U1.104 (PD14), U2.2 (DQ0)
/MEM_PD15: U1.105 (PD15), U2.4 (DQ1)
/MEM_PE0: U1.169 (PE0), U2.15 (DQML)
/MEM_PE1: U1.170 (PE1), U2.39 (DQMH)
/MEM_PE7: U1.68 (PE7), U2.8 (DQ4)
/MEM_PE8: U1.69 (PE8), U2.10 (DQ5)
/MEM_PE9: U1.70 (PE9), U2.11 (DQ6)
/MEM_PE10: U1.73 (PE10), U2.13 (DQ7)
/MEM_PE11: U1.74 (PE11), U2.42 (DQ8)
/MEM_PE12: U1.75 (PE12), U2.44 (DQ9)
/MEM_PE13: U1.76 (PE13), U2.45 (DQ10)
/MEM_PE14: U1.77 (PE14), U2.47 (DQ11)
/MEM_PE15: U1.78 (PE15), U2.48 (DQ12)
/MEM_PF0: U1.16 (PF0), U2.23 (A0)
/MEM_PF1: U1.17 (PF1), U2.24 (A1)
/MEM_PF2: U1.18 (PF2), U2.25 (A2)
/MEM_PF3: U1.19 (PF3), U2.26 (A3)
/MEM_PF4: U1.20 (PF4), U2.29 (A4)
/MEM_PF5: U1.21 (PF5), U2.30 (A5)
/MEM_PF11: U1.59 (PF11), U2.18 (~RAS~)
/MEM_PF12: U1.60 (PF12), U2.31 (A6)
/MEM_PF13: U1.63 (PF13), U2.32 (A7)
/MEM_PF14: U1.64 (PF14), U2.33 (A8)
/MEM_PF15: U1.65 (PF15), U2.34 (A9)
/MEM_PG0: U1.66 (PG0), U2.22 (A10)
/MEM_PG1: U1.67 (PG1), U2.35 (A11)
/MEM_PG2: U1.106 (PG2), U2.36 (A12)
/MEM_PG4: U1.108 (PG4), U2.20 (BA0)
/MEM_PG5: U1.109 (PG5), U2.21 (BA1)
/MEM_PG8: U1.112 (PG8), U2.38 (CLK)
/MEM_PG15: U1.160 (PG15), U2.17 (~CAS~)
/MEM_PH5: U1.46 (PH5), U2.16 (~WE~)
/MEM_PH6: U1.83 (PH6), U2.19 (~CS~)
/MEM_PH7: U1.84 (PH7), U2.37 (CKE)
/OSC: J1.30 (OSC), U12.9 (A7)
/OTG_HS_ULPI_CK: U1.51 (PA5), U15.2 (CLKOUT)
/OTG_HS_ULPI_D0: U1.47 (PA3), U15.4 (DATA0)
/OTG_HS_ULPI_D1: U1.56 (PB0), U15.5 (DATA1)
/OTG_HS_ULPI_D2: U1.57 (PB1), U15.6 (DATA2)
/OTG_HS_ULPI_D3: U1.79 (PB10), U15.7 (DATA3)
/OTG_HS_ULPI_D4: U1.80 (PB11), U15.8 (DATA4)
/OTG_HS_ULPI_D5: U1.92 (PB12), U15.10 (DATA5)
/OTG_HS_ULPI_D6: U1.93 (PB13), U15.11 (DATA6)
/OTG_HS_ULPI_D7: U1.163 (PB5), U15.12 (DATA7)
/OTG_HS_ULPI_DIR: U1.34 (PC2_C), U15.1 (DIR)
/OTG_HS_ULPI_NXT: U1.35 (PC3_C), U15.3 (NXT)
/OTG_HS_ULPI_STP: U1.32 (PC0), U15.24 (STP)
/SPARE1_DIR: U1.94 (PB14), U8.2 (DIR)
/SPARE2_DIR: U1.25 (PF7), U13.2 (DIR)
/SWCLK: J5.4 (SWCLK), U1.137 (PA14)
/SWDIO: J5.2 (SWDIO), U1.124 (PA13)
/SWO: J5.6 (SWO), U1.161 (PB3)
/TC: J1.27 (TC), U12.6 (A4)
/USB_FS_D+: J4.A6 (D+), J4.B6 (D+), U1.123 (PA12), U14.3 (IO2)
/USB_FS_D-: J4.A7 (D-), J4.B7 (D-), U1.122 (PA11), U14.1 (IO1)
/USB_HS+: J2.A6 (D+), J2.B6 (D+), U15.13 (DP)
/USB_HS-: J2.A7 (D-), J2.B7 (D-), U15.14 (DM)
/VBAT: U1.6 (VBAT)
/~ADDRESS_OE: R42.2, U1.130 (PH15), U9.22 (~OE), U10.22 (~OE), U11.22 (~OE)
/~CONTROL1_OE: R43.2, U1.147 (PD5), U4.22 (~OE)
/~CONTROL2_OE: R44.2, U1.89 (PH12), U7.22 (~OE)
/~CONTROL3_OE: R45.2, U1.28 (PF10), U12.22 (~OE)
/~DACK1: J1.17 (~DACK1), U12.3 (A1)
/~DACK2: J1.26 (~DACK2), U12.4 (A2)
/~DACK3: J1.15 (~DACK3), U12.5 (A3)
/~DATA_OE: R41.2, U1.145 (PD3), U3.22 (~OE)
/~IOR: J1.14 (~IOR), R37.2, U4.3 (A1)
/~IOW: J1.13 (~IOW), R38.2, U4.4 (A2)
/~IO_CH_CK: J1.32 (IO), R36.2, U6.10 (A8)
/~IRQ_OE: R46.2, U1.128 (PH13), U6.22 (~OE)
/~LV_DACK1: U1.44 (PH3), U12.21 (B1)
/~LV_DACK2: U1.43 (PH2), U12.20 (B2)
/~LV_DACK3: U1.40 (PA0), U12.19 (B3)
/~LV_IOR: U1.168 (PB9), U4.21 (B1)
/~LV_IOW: U1.167 (PB8), U4.20 (B2)
/~LV_IO_CH_CK: U1.110 (PG6), U6.14 (B8)
/~LV_NOWS: U1.42 (PA2), U12.16 (B6)
/~LV_SMEMR: U1.165 (PB7), U4.19 (B3)
/~LV_SMEMW: U1.164 (PB6), U4.18 (B4)
/~NOWS: J1.8 (UNUSED), U12.8 (A6)
/~REFRESH: J1.19 (~DACK0), R49.2, U1.162 (PB4)
/~RESET: C33.1, J5.3 (~RESET), R8.1, SW1.2, U1.31 (NRST), U15.22 (~RESETB)
/~SMEMR: J1.12 (~SMEMR), R39.2, U4.5 (A3)
/~SMEMW: J1.11 (~SMEMW), R40.2, U4.6 (A4)
/~SPARE1_OE: R47.2, U1.85 (PH8), U8.22 (~OE)
/~SPARE2_OE: R48.2, U1.26 (PF8), U13.22 (~OE)
GND: C1.2, C2.1, C3.2, C4.2, C5.1, C6.2, C7.2, C8.2, C9.1, C10.1, C11.1, C12.2, C13.2, C14.2, C15.2, C16.2, C17.2, C18.2, C19.2, C20.2, C21.2, C22.2, C23.2, C24.2, C25.2, C26.2, C27.2, C28.2, C29.2, C30.2, C31.2, C32.2, C33.2, C34.2, C35.2, C36.2, C37.2, C38.1, C39.2, C40.2, C41.2, C42.2, C43.2, C44.2, C45.2, C46.2, C47.2, C48.2, C49.2, C50.2, C51.2, C52.2, C53.2, C54.2, C55.2, C56.2, C57.2, C58.2, C59.2, J1.1 (GND), J1.10 (GND), J1.31 (GND), J2.A1 (GND), J2.A12 (GND), J2.B1 (GND), J2.B12 (GND), J2.S1 (SHIELD), J3.3, J4.A1 (GND), J4.A12 (GND), J4.B1 (GND), J4.B12 (GND), J4.S1 (SHIELD), J5.5 (GND), R13.1, R14.2, R15.1, R16.2, R20.2, R21.1, R22.1, R23.1, R24.1, R25.1, R26.1, R27.1, R28.1, R29.1, R30.1, R31.1, R32.1, R33.1, R34.1, SW1.1, U1.14 (VSS), U1.22 (VSS), U1.37 (VSSA), U1.48 (VSS), U1.61 (VSS), U1.71 (VSS), U1.90 (VSS), U1.102 (VSS), U1.113 (VSS), U1.126 (VSS), U1.135 (VSS), U1.148 (VSS), U1.158 (VSS), U2.6 (VSSQ), U2.12 (VSSQ), U2.28 (VSS), U2.41 (VSS), U2.46 (VSSQ), U2.52 (VSSQ), U2.54 (VSS), U3.11 (GND), U3.12 (GND), U3.13 (GND), U4.10 (A8), U4.11 (GND), U4.12 (GND), U4.13 (GND), U4.14 (B8), U5.1 (GND), U6.11 (GND), U6.12 (GND), U6.13 (GND), U7.6 (A4), U7.7 (A5), U7.8 (A6), U7.9 (A7), U7.10 (A8), U7.11 (GND), U7.12 (GND), U7.13 (GND), U7.14 (B8), U7.15 (B7), U7.16 (B6), U7.17 (B5), U7.18 (B4), U8.11 (GND), U8.12 (GND), U8.13 (GND), U9.11 (GND), U9.12 (GND), U9.13 (GND), U10.11 (GND), U10.12 (GND), U10.13 (GND), U11.3 (A1), U11.4 (A2), U11.5 (A3), U11.6 (A4), U11.11 (GND), U11.12 (GND), U11.13 (GND), U11.18 (B4), U11.19 (B3), U11.20 (B2), U11.21 (B1), U12.10 (A8), U12.11 (GND), U12.12 (GND), U12.13 (GND), U12.14 (B8), U13.11 (GND), U13.12 (GND), U13.13 (GND), U14.2 (VN), U15.25 (GND), X1.2 (GND), Y1.2, Y1.4
unnamed: C1.1, U1.81 (VCAP1)
unnamed: C2.2, U1.125 (VCAP2)
unnamed: C3.1, R17.2, U15.20 (XO), Y1.1
unnamed: C4.1, J2.A4 (VBUS), J2.A9 (VBUS), J2.B4 (VBUS), J2.B9 (VBUS), R18.2
unnamed: C5.2, U1.29 (PH0), Y2.1
unnamed: C6.1, U1.30 (PH1), Y2.2
unnamed: C7.1, R2.2, U1.38 (VREF+)
unnamed: C8.1, R17.1, U15.21 (REFCLK/XI), Y1.3
unnamed: C10.2, U15.15 (VDD33), U15.18 (ID)
unnamed: C11.2, U15.23 (VDD18)
unnamed: D1.1 (K), R21.2
unnamed: D2.1 (K), R22.2
unnamed: D3.1 (K), R23.2
unnamed: D4.1 (K), R24.2
unnamed: D5.1 (K), R25.2
unnamed: J2.A5 (CC1), R13.2
unnamed: J2.B5 (CC2), R14.1
unnamed: J3.2, R7.1
unnamed: J4.A4 (VBUS), J4.A9 (VBUS), J4.B4 (VBUS), J4.B9 (VBUS), JP1.1 (A), U14.5 (VP)
unnamed: J4.A5 (CC1), R15.2
unnamed: J4.B5 (CC2), R16.1
unnamed: R1.1, U1.171 (PDR_ON)
unnamed: R18.1, U15.17 (VBUS)
unnamed: R19.1, U15.19 (RBIAS)
unnamed: R19.2, R20.1
unnamed: U12.15 (B7), X1.3 (OUT)

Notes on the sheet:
SDRAM
CPU

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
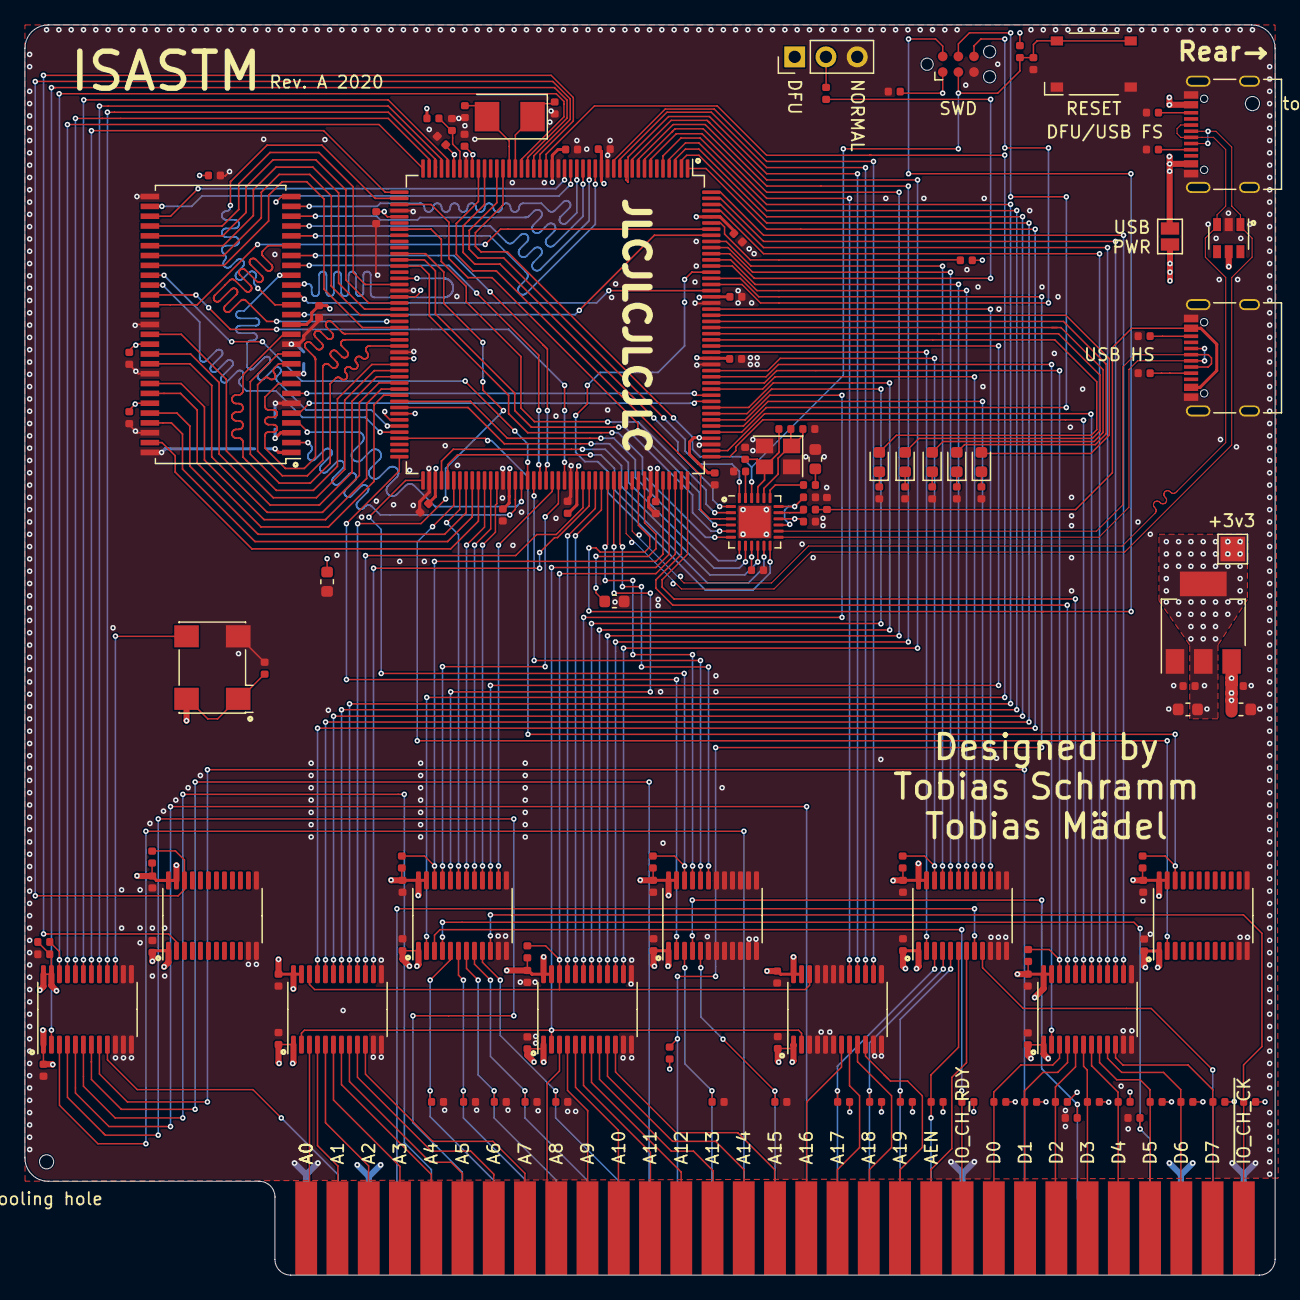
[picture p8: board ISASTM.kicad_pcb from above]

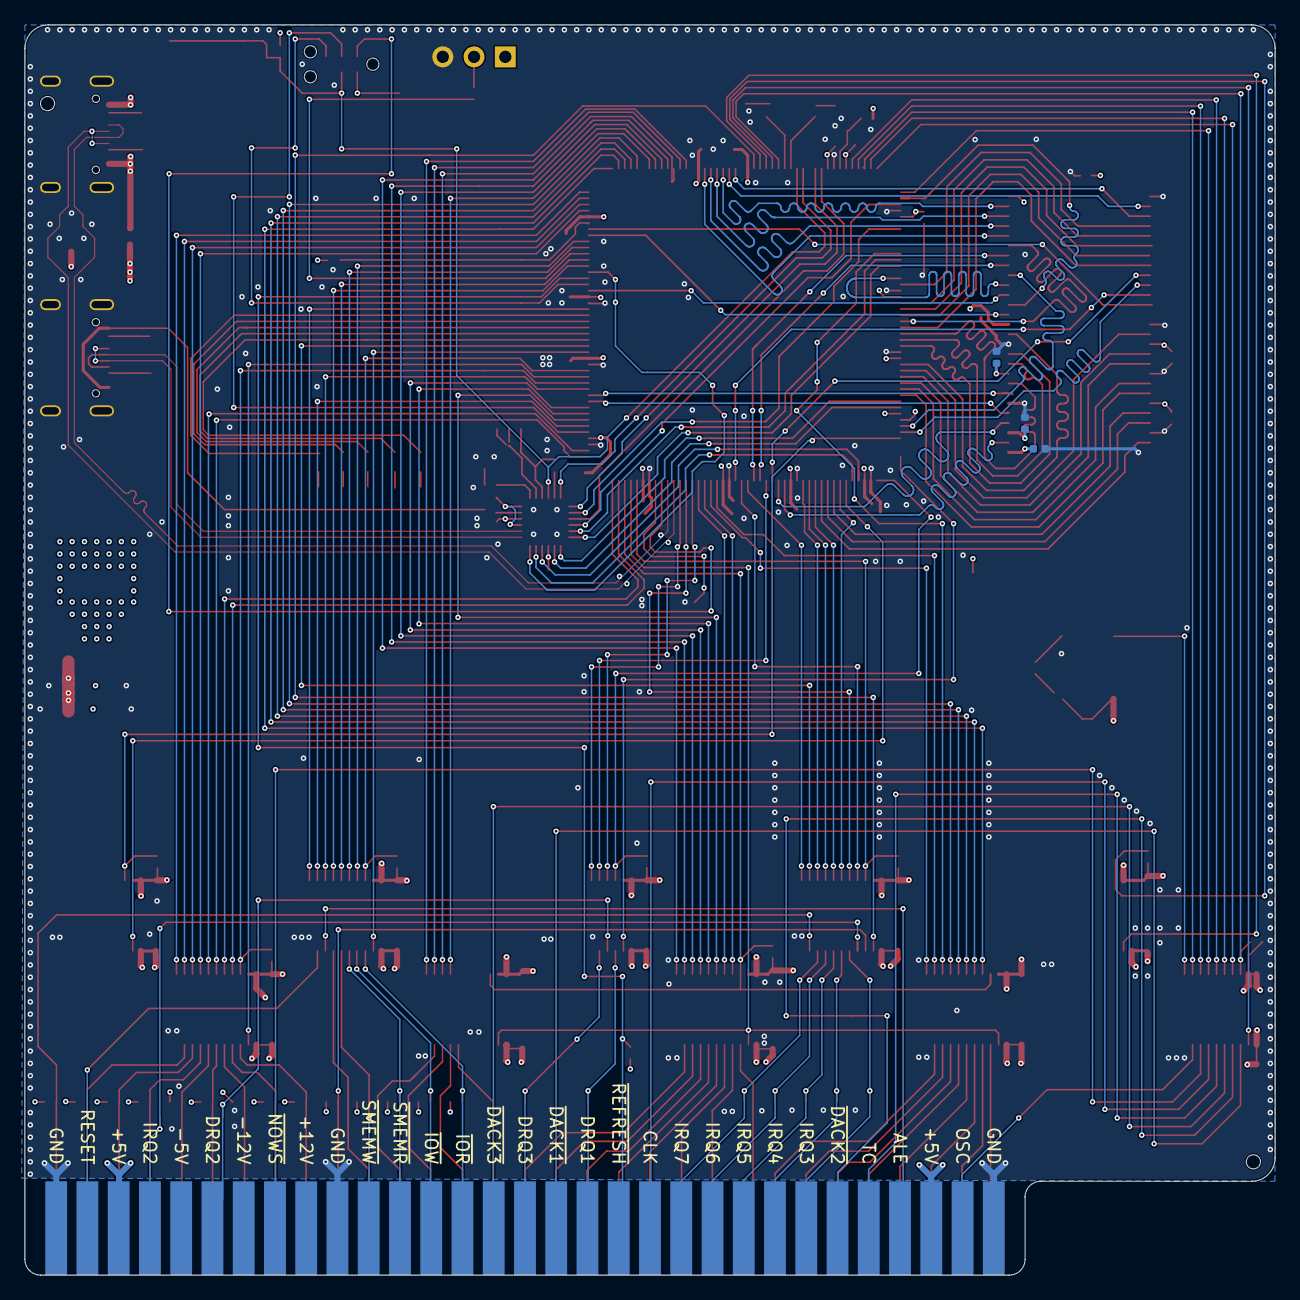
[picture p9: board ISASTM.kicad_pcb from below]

Board: 4 copper layers, 101.6 x 101.6 mm, 141 parts (3 on the bottom side), 216 nets.

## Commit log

2020-09-13 Add connector
    [ISASTM-B_Cu.gbl, ISASTM-B_Mask.gbs, ISASTM-B_Paste.gbp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]
2020-09-19 Add ISA bus, level shifters, memory pinout
    [ISASTM.kicad_pcb, ISASTM.sch]
2020-09-19 Add USB PHY, USB connectors, pull ups, DRQ/IRQ
    [ISASTM.sch]
2020-09-19 Add more decoupling
    [ISASTM.kicad_pcb, ISASTM.sch]
2020-09-19 Finish fanout and ULPI routing
    [ISASTM.kicad_pcb, ISASTM.sch]
2020-09-20 Partial ISA bus layout
    [ISASTM.kicad_pcb, ISASTM.sch]
2020-09-21 Route LV bus
    [ISASTM.kicad_pcb, ISASTM.sch]
2020-09-21 Place bias resistors
    [ISASTM.kicad_pcb, ISASTM.sch]
2020-09-21 Hook up ISA address + data
    [ISASTM.kicad_pcb]
2020-09-21 Finish ISA signal routing
    [ISASTM.kicad_pcb]
2020-09-22 Finish routing
    [ISASTM.kicad_pcb]
2020-09-22 Stitch board edge
    [ISASTM.kicad_pcb]
2020-09-22 Finish GND stitching
    [ISASTM.kicad_pcb]
2020-09-22 Hide all footprint references
    [ISASTM.kicad_pcb]
2020-09-22 Add ISA signal labels
    [ISASTM.kicad_pcb]
2020-09-22 Add 3v3 testpoint
    [ISASTM.kicad_pcb, ISASTM.sch]
2020-09-22 Add tooling holes
    [ISASTM.kicad_pcb, ISASTM.sch]
2020-09-22 Match USB FS trace length
    [ISASTM.kicad_pcb]
2020-09-22 Prettier silkscreen markings, aesthetic fixes for traces
    [ISASTM.kicad_pcb]
2020-09-22 Add 3D model configuration, rendered pictures of RevA
    [ISASTM-B_Cu.gbl, ISASTM-B_Mask.gbs, ISASTM-B_Paste.gbp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]
2020-09-22 Fix missing ~REFRESH resistor, add better renders
    [ISASTM.kicad_pcb, ISASTM.sch]
2020-09-22 Add readme, schematic PDF, ibom, gerbers and change DRAM
    [ISASTM-B_Cu.gbl, ISASTM-B_Mask.gbs, ISASTM-B_Paste.gbp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]
